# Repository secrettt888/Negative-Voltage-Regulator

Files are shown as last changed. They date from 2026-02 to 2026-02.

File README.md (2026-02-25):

# Discrete Negative Voltage Regulator

A fully discrete negative voltage regulator built entirely from transistors and passive components (no integrated circuits). This repository contains the complete design pipeline, including the OrCAD schematic, PSpice simulation, and PCB layout.

NVR

## ⚡ Specifications
* **Input Voltage (Vin):** -40V to -37V
* **Output Voltage (Vout):** -34V to -32V (Adjustable)
* **Max Output Current:** 44mA
* **Output Resistance:** <= 4Ω
* **Stability Factor:** > 60

## 📂 Repository Contents
* **/Hardware/OrCAD_Source:** OrCAD source files and PDF schematics.
* **/Hardware/Fabrication:** Board layout files, 3D models, and production-ready Gerbers.
* **/Simulation:** PSpice `.sim` files and waveform plots.
* **/Docs:** Component datasheets and the Bill of Materials (BOM).

## 🧠 Theory of Operation



The circuit relies entirely on discrete components to achieve stable voltage regulation and fault protection:

1. **Voltage Reference:** A 10V Zener diode establishes the baseline stable voltage.
2. **Current Source:** A current mirror, taking the Zener diode as its reference, provides stable biasing.
3. **Error Amplifier:** A PNP differential pair compares the 10V reference to the scaled output voltage provided by the feedback network.
4. **Negative Feedback Network:** Formed by a resistor divider and a trimmer potentiometer, allowing the user to precisely vary and set the output voltage.
5. **Pass Element:** A Darlington transistor configuration is used to efficiently regulate the current delivered to the load.
6. **Overvoltage Protection (OVP):** Implemented using a combination of a Darlington transistor and multiple diodes to clamp unsafe voltage spikes.
7. **Overcurrent Protection (OCP):** Features a foldback current limiting circuit to safely reduce power dissipation in the pass element during a short circuit or heavy overload.

## 📈 Simulation Results
**OCP:** Overcurrent_protection
**OVP:** Overvoltage_protection

## 🏁 Quick Start
1. **Simulate:** Open the files in `/Hardware/OrCAD_Source` in PSpice to view the transient response, line/load regulation, and foldback protection behavior. 
2. **Fabricate:** Use the Gerber files located in `/Hardware/Fabrication` to order your printed circuit boards.
3. **Build:** Populate the components according to the `BOM.pdf` found in the `/Docs` folder.

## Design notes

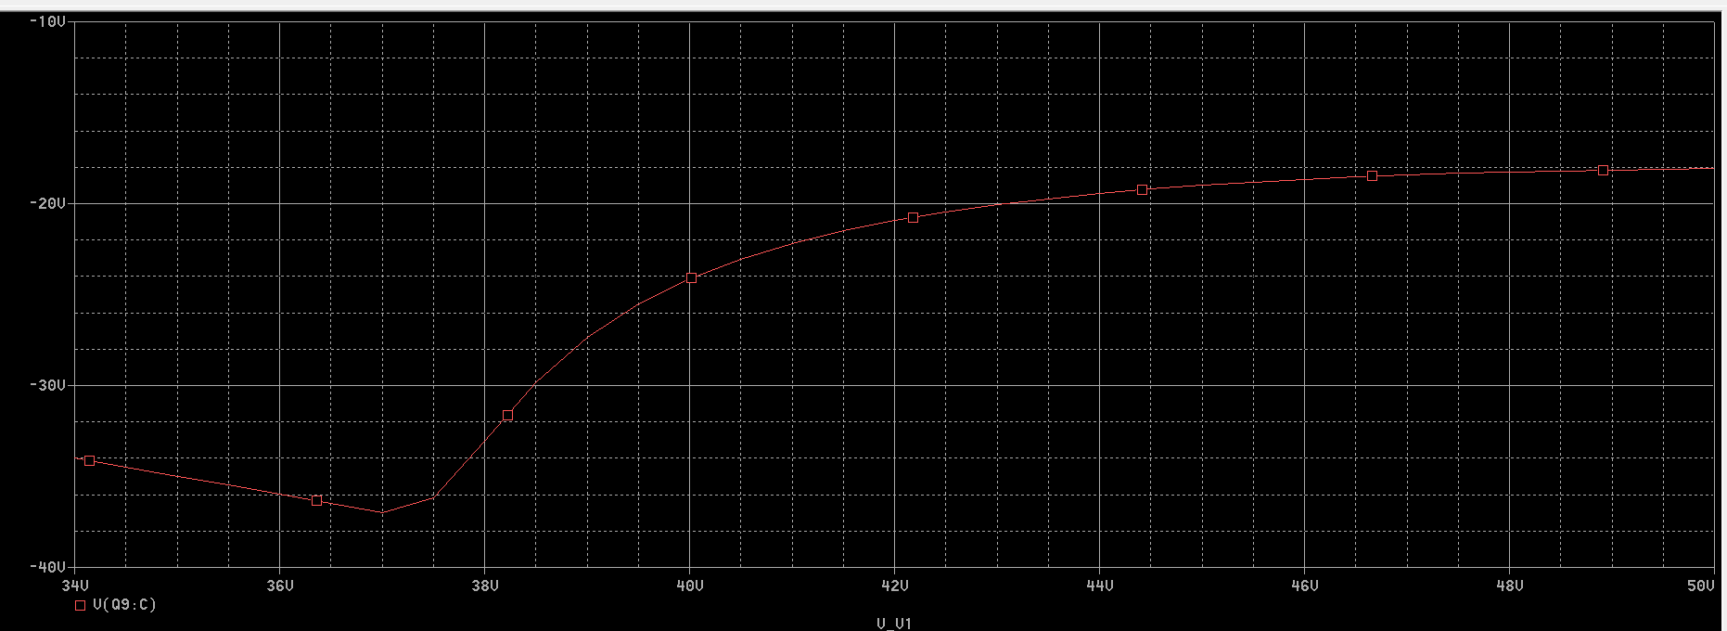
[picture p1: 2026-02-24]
Simulation/Overvoltage_protection.png

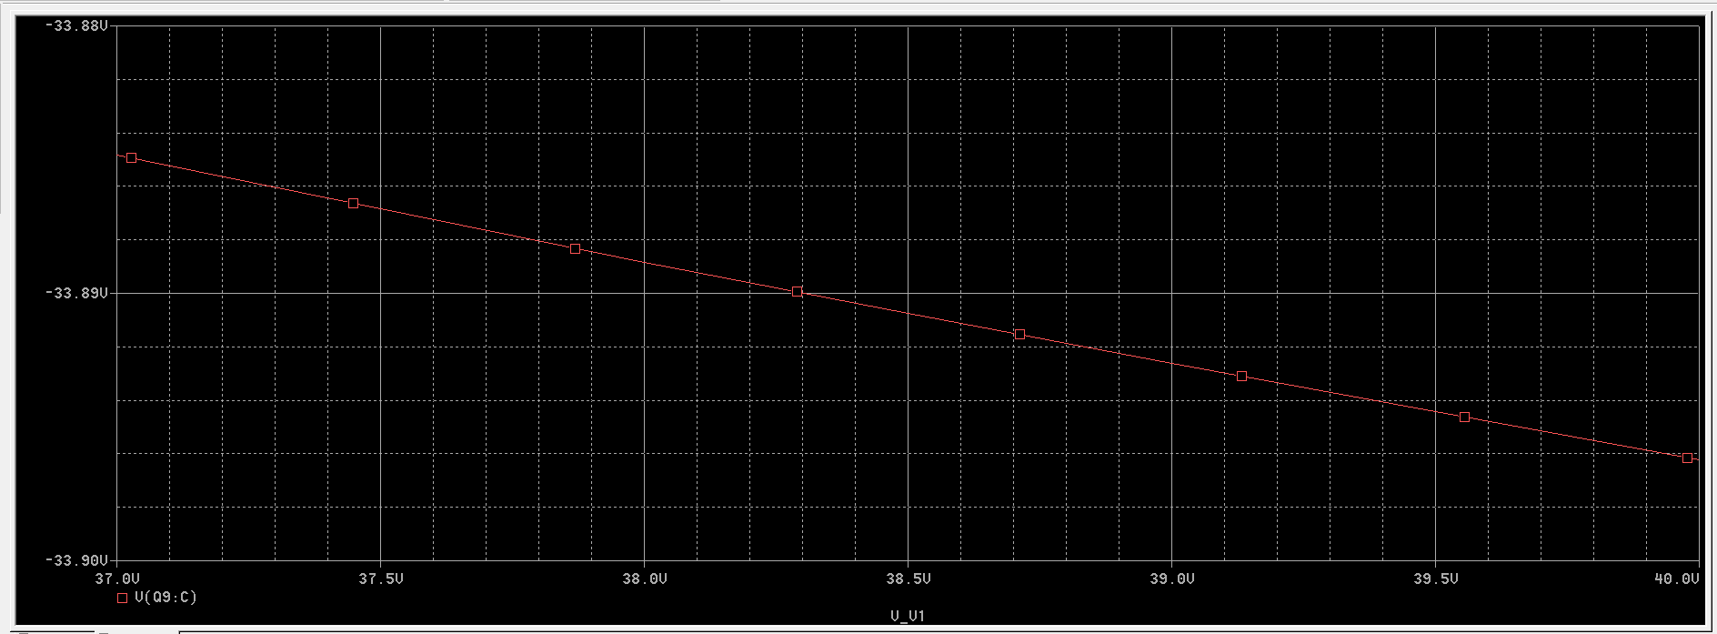
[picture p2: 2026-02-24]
Simulation/Line_regulation(-34V).png

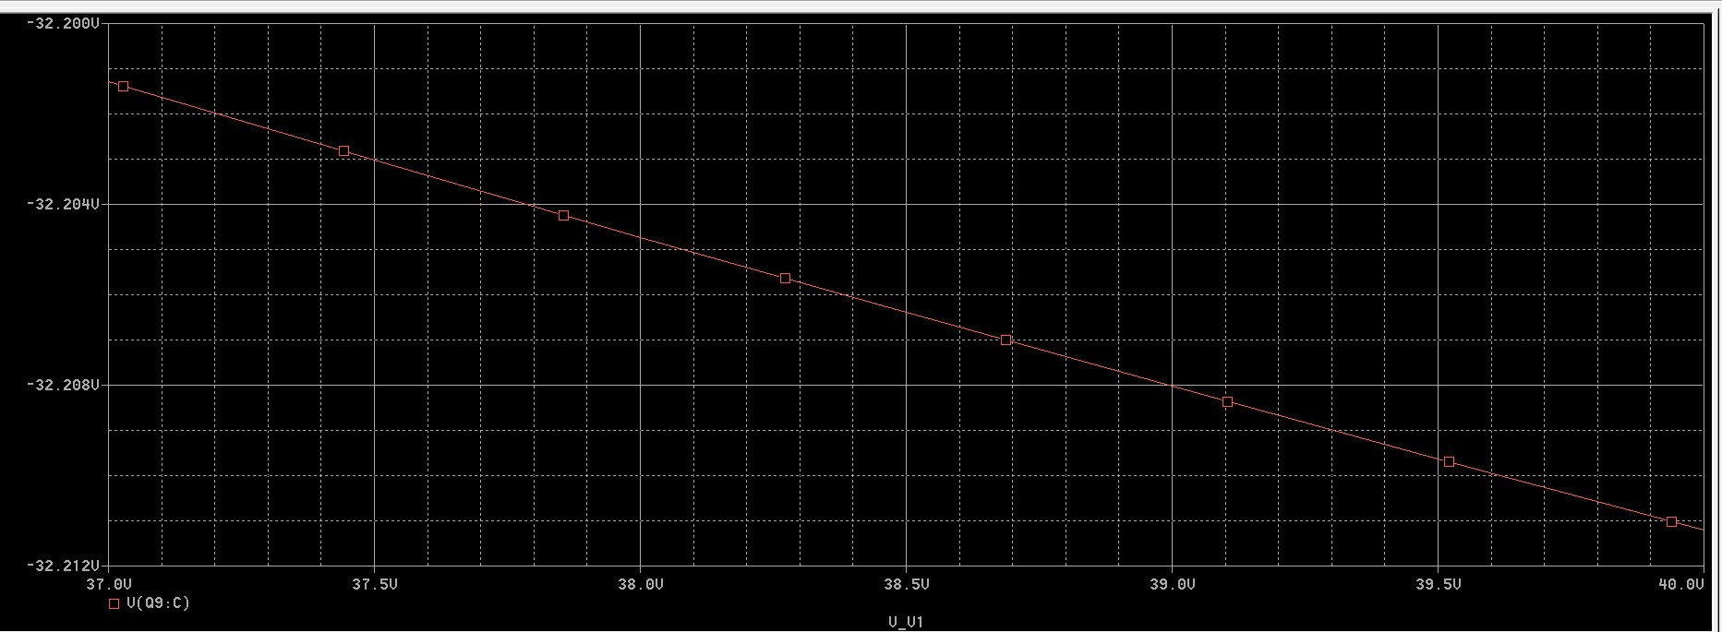
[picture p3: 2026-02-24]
Simulation/Line_regulation(-32V).png

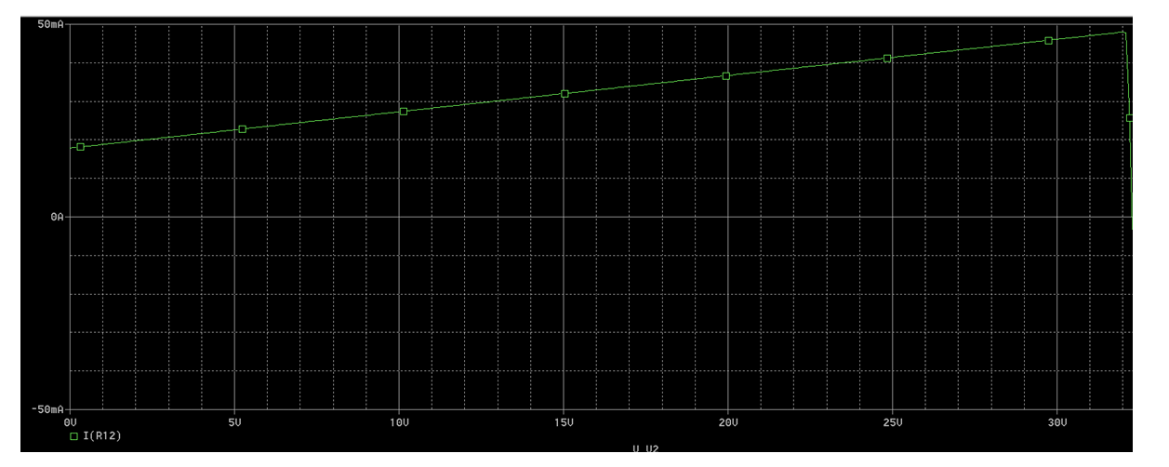
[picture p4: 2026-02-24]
Simulation/Overcurrent_protection.png

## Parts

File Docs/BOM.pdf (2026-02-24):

Value | Catalog Link | Part Number | Manufacturer | Description | Ref Defs
4.7uF | (LINK) (https://www.tme.eu/ro/details/cl21a475kaqnnng/condensatoare-mlcc-smd-0805/samsung/) | CL21A475K AQNNNG | SAMSUNG | ceramic capacitor MLCC; 4,7uF; 25V; X5R; ±10%; SMD; 0805 | C1,C2,C3
10V | (LINK) (https://www.tme.eu/ro/details/bzx84-c10.215/diode-zener-smd/nexperia/) | BZX84-C10 | NEXPERIA | Zener diode, SMD, SOT23, 10V, ±5%, 0.3W | D1, D3, D5, D6, D7
6.8V | (LINK) (https://www.tme.eu/ro/details/bzx84-c6v8.215/diode-zener-smd/nexperia/) | BZX84-C6V8 | NEXPERIA | Zener diode, SMD, SOT23, 6.8V, ±5%, 0.3W | D2,D4
PNP | (LINK) (http://www.tme.eu/ro/details/bc807-25-dio/tranzistori-smd-pnp/diotec-semiconductor/bc807-25/) | BC807-25-DIO | NXP | PNP transistor, SMD, SOT23, 45V, 800mA | Q1,Q2,Q3,Q 4
PNP | (LINK) (http://www.tme.eu/ro/details/mjd32cg/tranzistori-smd-pnp/on-semiconductor/) | MJD32CG | ON Semiconducto r | PNP transistor, SMD, DPACK, 100V, 3A, 15W | Q7,Q9
NPN | (LINK) (http://www.tme.eu/ro/details/bc817-25-dio/tranzistori-smd-npn/diotec-semiconductor/bc817-25/) | BC817-25-DIO | NXP | NPN transistor, SMD, SOT23, 45V, 800mA | Q5,Q6
22k | (LINK) (https://www.tme.eu/ro/details/smd0805-22k/rezistente-smd-0805/royal-ohm/0805s8j0223t5e/) | 0805S8J022 3T5E | ROYAL OHM | SMD Resistor, chip, 0805, 22kΩ, ±5%, 0.125W | R1
330 | (LINK) (https://www.tme.eu/ro/details/smd0805-330r/rezistente-smd-0805/royal-ohm/0805s8j0331t5e/) | 0805S8J033 1T5E | ROYAL OHM | SMD Resistor, chip, 0805, 330Ω, ±5%, 0.125W | R2,R3,R10
3.3k | (LINK) (https://www.tme.eu/ro/details/smd0805-3k3/rezistente-smd-0805/royal-ohm/0805s8j0332t5e/) | 0805S8J033 2T5E | ROYAL OHM | SMD Resistor, chip, 0805, 3.3kΩ, ±5%, 0.125W | R4,R7
47k | (LINK) (http://www.tme.eu/ro/details/smd0805-47k/rezistente-smd-0805/royal-ohm/0805s8j0473t5e/) | 0805S8J047 3T5E | ROYAL OHM | SMD Resistor, thick film; 0805; 47kΩ; 0,125W; ±5%; -55÷125°C | R6
15k | (LINK) (https://www.tme.eu/ro/details/smd0805-15k/rezistente-smd-0805/royal-ohm/0805s8j0153t5e/) | 0805S8J015 3T5E | ROYAL OHM | SMD Resistor, chip, 0805, 15kΩ, ±5%, 0.125W | R8

1 | (LINK) (https://www.tme.eu/ro/details/smd0805-1r/rezistente-smd-0805/royal-ohm/0805s8j010jt5e/) | 0805S8J010 JT5E | ROYAL OHM | Rezistor SMD, chip, 0805, 1Ω, ±5%, 0.125W | R9
33 | (LINK) (https://www.tme.eu/ro/details/smd0805-33r/rezistente-smd-0805/royal-ohm/0805s8j0330t5e/) | 0805S8J033 0T5E | ROYAL OHM | SMD Resistor, chip, 0805, 33Ω, ±5%, 0.125W | R12
10k | (LINK) (https://www.tme.eu/ro/details/smd0805-10k/rezistente-smd-0805/royal-ohm/0805s8j0103t5e/) | 0805S8J010 3T5E | ROYAL OHM | SMD Resistor, chip, 0805, 10kΩ, ±5%, 0.125W | R11
1k | (LINK) (https://www.tme.eu/ro/details/smd0805-1k/rezistente-smd-0805/royal-ohm/0805s8j0102t5e/) | 0805S8J010 2T5E | ROYAL OHM | SMD Resistor, chip, 0805, 1kΩ, ±5%, 0.125W | R13,R14
2.7k | (LINK) (https://www.tme.eu/ro/details/smd0805-2k7/rezistente-smd-0805/royal-ohm/0805s8j0272t5e/) | 0805S8F270 1T5E | ROYAL OHM | SMD Resistor, chip, 0805, 2.7kΩ, ±5%, 0.125W | R15
1.5k | (LINK) (https://www.tme.eu/ro/details/wf08p-1k5-5%25/rezistente-smd-0805/walsin/wf08p152jtl/) | WF08P152J TL | WALSIN | SMD Resistor, chip, 0805, 1.5kΩ, ±5%, 0.125W | R16
2.2k | (LINK) (https://www.tme.eu/ro/details/smd0805-2k2/rezistente-smd-0805/royal-ohm/0805s8j0222t5e/) | 0805S8J022 2T5E | ROYAL OHM | SMD Resistor, chip, 0805, 2.2kΩ, ±5%, 0.125W | R20
50k | (LINK) (http://www.tme.eu/ro/details/3314g-1-503e/trimere-smd-cu-o-singura-tura/bourns/) | 3314G-1-503E | BOURNS | Potențiome-SMD Single-Turn Linear Trimmer, 50kΩ, ±20% | R17

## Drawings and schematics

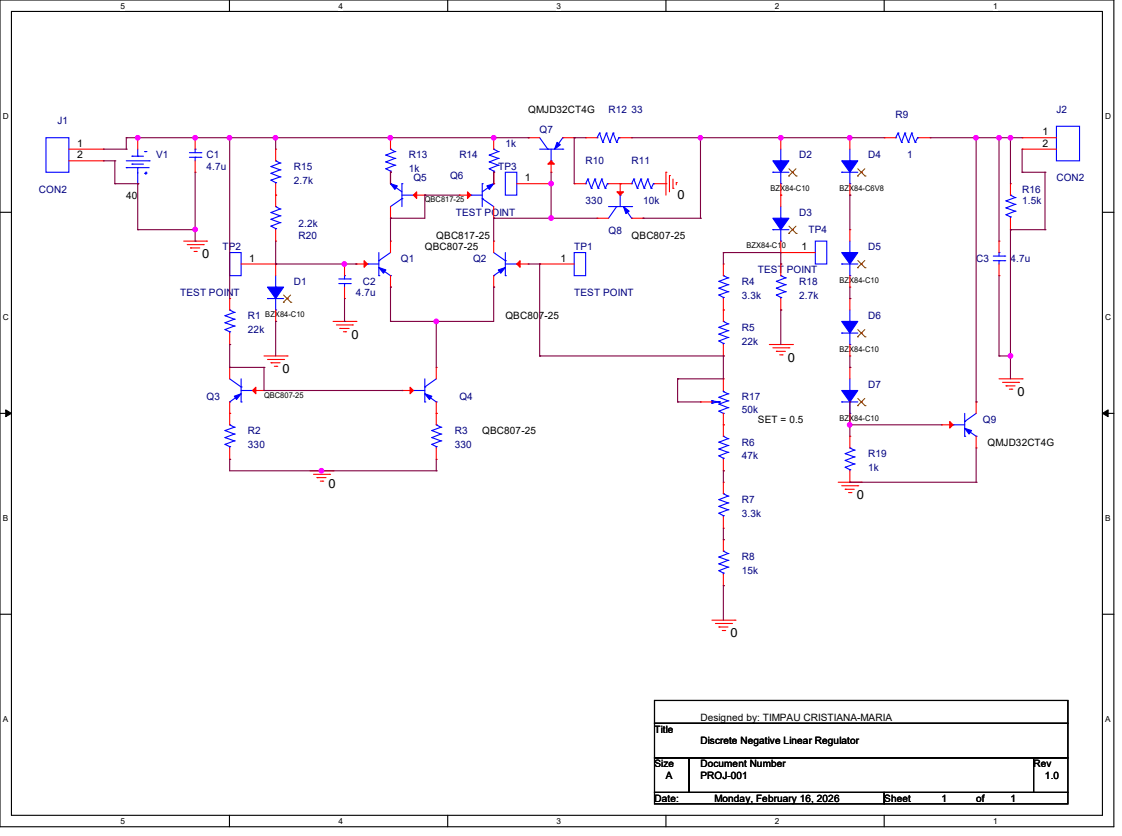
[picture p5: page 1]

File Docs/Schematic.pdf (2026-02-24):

0

0
